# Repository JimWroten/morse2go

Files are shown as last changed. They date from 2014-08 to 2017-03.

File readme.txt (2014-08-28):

Morse2Go is a small portable device that helps people with disabilities communicate. 
Specifically, the target users include people with disabilities involving speech and 
movement. But by moving a finger, toe, arm, head or using a puff/sip mouth switch, 
a person can key text messages into the M2G. Their words will be displayed on a 
small LCD screen, smartphone or computer. 

The M2G is an Arduino Due project. The source code consists of three files m2g_1.ino,
m2g.cpp and m2g.h. In addition, the libraries Adafruit_CC3000 and Stopwatch are used,
in addition to the standard Arduino libraries.

See www.morse2go.org for more information.

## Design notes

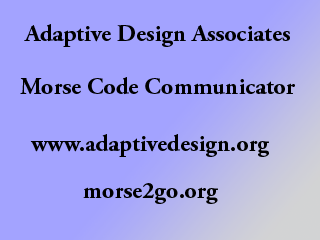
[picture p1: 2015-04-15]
m2g_2/m2g.bmp

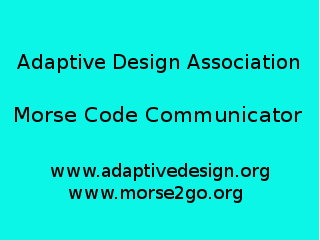
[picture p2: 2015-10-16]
m2g_21/m2g.bmp

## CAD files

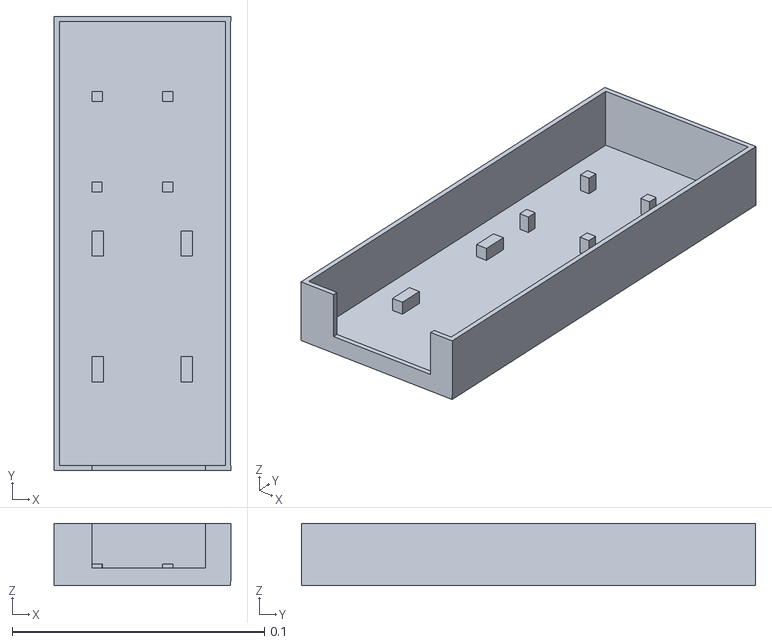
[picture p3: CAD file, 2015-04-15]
m2g_2_case/m2g_case.stl
0.07 x 0.18 x 0.0247

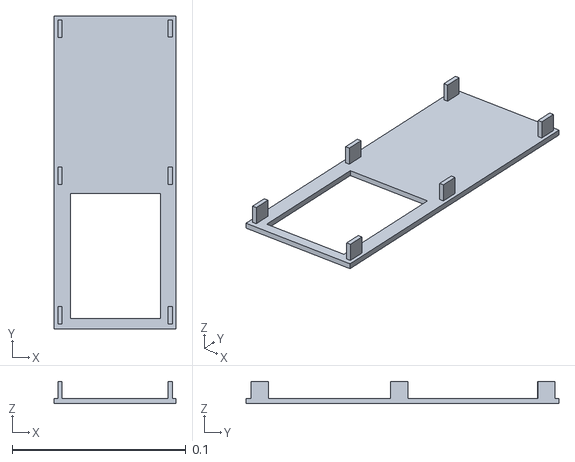
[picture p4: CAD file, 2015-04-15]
m2g_2_case/m2g_top.stl
0.07 x 0.18 x 0.0128

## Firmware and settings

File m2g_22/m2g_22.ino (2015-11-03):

/* Morse2Go
A communication device for persons with language and movement disabilities.
For more information, please visit -- www.morse2go.org

This device accepts Morse Code input from either one key switch or two keys
and translates the codes onto an LCD screen. Display can also be seen on a
Smartphone or a Computer Monitor.

The hardware is based on the Arduino Mega 2560 and Adafruit 2.8" TFT display.
Morse Code patterns and user defined abbreviations are stored on a micro SD card
so that code modifications can be made without changing program code.

Developed jointly by Adaptive Design Association, NYC (www.adaptivedesign.org),
and Jim Wroten, Technical Consultant (www.jimwroten.nyc).

This work is licensed 2015 by Jim Wroten (www.jimwroten.nyc) under a Creative
Commons Attribution-ShareAlike 4.0 International License. For more information
about this license, see www.creativecommons.org/licenses/by-sa/4.0/
-- Basically, you can use this software for any purpose for free,
as long as you say where you got it and that if you modify it, you don't remove
any lines above THIS line:
---------------------------------------------------------------

------------------ Release History  ---------------------------

9/6/14 Initial Release 1.0
  - basic functionality - user input of 1 or 2 button code
  - morse2go code table input from Google docs - support for mcode, scode and pcode
  - user input of timing values. persistent pcode values saved in usr_parm.csv file on Micro SD
  - basic checking of user input parmameters (pcode) upper and lower limits, 10% max change limits
  - /D delete - deletes the usr_parm.csv file and reboots. This brings in factory default timings
  - /L list - list current timing paramters
  - TODO: user input of short codes

10/1/14 Release 2.0
  - moved to Arduino Mega 2560 platform with Adafruit 2.8" TFT LCD shield and Micro SD card - reduces assembly complexity
  - added EMIC 2 text-to-speech module
  - construction note: Using the Adafruit 2.8" TFT with the Mega 2560 requires soldering closed the three ICSP jumpers,
  near the 6 pin jack. See: https://learn.adafruit.com/adafruit-2-8-tft-touch-shield-v2/connecting - search "Using with a Mega".
  It isn't necessary to cut the small line in between the #11, #12, #13 pads.

4/1/15 Release 2.1
  - Simplified user modified parameters - only saving the last change to parameters, which overrides the Google Doc parameters (pcodes)
  - Added pcodes /vc (voice)
  - removed one button operation - use button 1 for dit, button 2 for dah
  - added enter key and delete key (buttons 3 and 4)
  -   enter key - press to accept last entry in buffer. If there is no last entry, insert space, third space - say it
  -   delete key - press to delete current buffer. If buffer is empty, delete last character on screen, third delete clear screen

11/10/15 Release 2.2
  - Two Button and Four Button modes - a long press of button 1 is the same as a button 3 press. Long press of button 2 
    is the same as button 4. 
  - Added codes for space (..--), backspace (----), speak (.---.), and clear (.._..). These are defined on code.csv
  - Formatted the TFT screen when words wrap
  - Moved Word Work Area to fifth line of TFT, separating it from the message area (lines 1 - 4). This simplifies the software
    design and gives the user more focus on the bottom three lines of the display. 
  - Added Long Press user control. By entering one of 13 codes (:L3 to :L9 and :LA to :LF) user can vary the lenght of a long press from 
    0.3 seconds to 1.5 seconds, respectively. This new value is saved for the next reboot. 
  - Added Voice Param user contral. By entering one of the 9 codes (:V0 ot :V8) the user can change the voice of the Text-to-Speech module.
    This new value is saved for the next reboot.   
*/

#include <Adafruit_GFX.h>    // Core graphics library
#include "Adafruit_ILI9341.h" // 2.8" touch screen
#include <SPI.h>
#include <SD.h>
#include <StopWatch.h>
#include <EEPROM.h>
#include "m2g.cpp"

#define TFT_DC 9
#define TFT_CS 10
Adafruit_ILI9341 tft = Adafruit_ILI9341(TFT_CS, TFT_DC);

// MicroSD
const int chipSelect = 4;
#define SD_CS 4

// data structure of morse code
mcodes mcode;

// data structure of short code
scodes scode;

// data structure of parameter code
pcodes pcode;

// data structure of a single letter
char_stk char_s;

// data structure of word stack
word_stk word_s;

// data structure of message stack
message_stk message_s;

// stopwatch -- used to time switch press
StopWatch SW;

// length of a long press (minimum in milliseconds)
int LongPress;

// voice parm
int Voice;

// flag that is set if long press done
int LongPress1, LongPress2, LongPress3;

// pin number can be changed
const int inPin1 = 41;     // button 1 - dit
int buttonState1 = HIGH;  // button state - dit
int lastButtonState1 = HIGH;
long lastDebounceTime1 = 0;  // the last time pin 1 was toggled
int readingPin1;  // current reading switch 1

// pin number can be changed
const int inPin2 = 43;     // button 2 - dah
int buttonState2 = HIGH;  // button state - dah
int lastButtonState2 = HIGH;
long lastDebounceTime2 = 0;  // the last time pin 2 was toggled
int readingPin2;  // current reading switch 2

// pin number can be changed
const int inPin3 = 47;     // button 3 - enter
int buttonState3 = HIGH;  // button state - enter
int lastButtonState3 = HIGH;
long lastDebounceTime3 = 0;  // the last time pin 3 was toggled
int readingPin3;  // current reading switch 3
short timesPressed3 = 0; // times enter key pressed in a row

// pin number can be changed
const int inPin4 = 49;     // button 4 - delete
int buttonState4 = HIGH;  // button state - delete
int lastButtonState4 = HIGH;
long lastDebounceTime4 = 0;  // the last time pin 3 was toggled
int readingPin4;  // current reading switch 4
short timesPressed4 = 0; // times delete key pressed in a row

const long debounceDelay = DEBOUNCEDELAY;     // delay in milliseconds

// voice param
int pr_vc = PRVC;
int pr_fn = PRFN;

// EEPROM data 
int Adr = 0;
EEPromData Eep;

int inp_ch = -1;

// done once to load classes and setup
void setup()
{
  char *p;
  int i = 0, j = 0, n = 0, k, r, c;
  int mode;
  char buf[20], buf1[20];
  int v[NPARMS];
  float f_longPress, f_voice;

  // Open serial communications and wait for port to open:
  Serial.begin(9600);

  // Open serial communications for EMIC 2 Text to Speech module
  // Pin18 is TX pin - connect to SIN on EMIC 2
  // Pin19 is RX pin - connect to SOUT on EMIC 2
  // NOTE: This code is specific to Arduino Mega

  Serial1.begin(9600);
  Serial1.print('\n');             // Send a CR in case the system is already up
  delay(20);
  while (Serial1.read() != ':');   // When the Emic 2 has initialized and is ready, it will send a single ':' character, so wait here until we receive it
  Serial1.flush();                 // Flush the receive buffer

  // read EEPROM data
  EEPROM.get(Adr, Eep);

  if (Eep.ckvalue != CKVALUE) {  // initialize first time if never used
      for (i = 0 ; i < EEPROM.length() ; i++)
        EEPROM.write(i, 0);

      Eep.ckvalue = CKVALUE;
      Eep.LongPress = LongPress = LONGPRESS;
      Eep.Voice = Voice = VOICE; 
      for (i = 0; i < 10; i++) 
          Eep.v[i] = 0; 
      EEPROM.put(Adr, Eep);
      sprintf(buf, "eeprom initialized - first time use");
      Serial.println(buf); 
  }
  else {
      LongPress = Eep.LongPress;
      Voice = Eep.Voice; 
      sprintf(buf, "Voice: %d, Long Press: %d\n", Voice, LongPress);
      Serial.println(buf);
  }
  sprintf(buf, "N%d\n", Voice); 
  Serial1.print(buf);
  Serial1.flush();                 // Flush the receive buffer

  LongPress3 = 0;

  // input keys setup
  pinMode(inPin1, INPUT);
  pinMode(inPin2, INPUT);
  pinMode(inPin3, INPUT);
  pinMode(inPin4, INPUT);

  digitalWrite(inPin1, HIGH);
  digitalWrite(inPin2, HIGH);
  digitalWrite(inPin3, HIGH);
  digitalWrite(inPin4, HIGH);

  // for Micro SD
  pinMode(chipSelect, OUTPUT);

  // see if the card is present and can be initialized:
  if (!SD.begin(chipSelect)) {
    tft.println(F("Card failed, or not present"));
    // don't do anything more:
    return;
  }

  // load data file from Google Docs copied onto Micro SD
  ReadDataFile(CODE);

  // load user parameter file if it exists
  ReadParmFile(USR_PARM);

  // sort the codes
  mcode.sortcode();

  // setup TFT screen
  tft.begin();
  tft.setTextColor(ILI9341_BLACK);
  tft.setTextSize(2);  // font param

  tft.setRotation(1);
  bmpDraw("m2g.bmp", 0, 0);
  delay(2000);
  
  tft.fillScreen(0xFFFF);
  setcursor(1, -1, 4, 4, &c, &r);
  tft.print(F("M2G Version 2.2"));
  delay(1000);

  f_longPress = (float)LongPress / 1000.0;
  dtostrf(f_longPress, 3, 1, buf1);
  sprintf(buf, "Long Press %s Sec.", buf1); 
  tft.fillScreen(0xFFFF);
  setcursor(1, -1, 2, 4, &c, &r);
  tft.print(buf);
  delay(1000);
  
  Serial1.print("S M 2 G Version 2.2\n");
  tft.setTextSize(pr_fn);  // font param
  cls(0);
  show_labels(0, 0);

}

// repeat this forever, checking for a keypress or key release event
void loop() {

  char buf[SIZMESG], buf1[SIZMESG];
  int timebtn1, timebtn2, timebtn3, timebtn4;
  int Btn1, Btn2, Btn3, Btn4, PushCode, clen, lenmesg, CurRow1, ptr, valLP, valVOZ ;
  int speakit, speaklen, new_word, csize, lenpword;
  char speaktxt[MAXWORD_TXT];
  char pword[SIZPWORD];
  char smesg[SIZMESG];
  char *pword1, *tok;
  static int PrvRow;
  static char s[2] = " ";
  float f_longPress;

  // check button status
  readingPin1 = digitalRead(inPin1);
  readingPin2 = digitalRead(inPin2);
  readingPin3 = digitalRead(inPin3);
  readingPin4 = digitalRead(inPin4);

  Btn1 = Btn2 = Btn3 = Btn4 = 0;
  PushCode = 0;
  LongPress1 = LongPress2 = 0;

  //  Button 1 - 4 Pressed
  if ((readingPin1 == LOW && lastButtonState1 == HIGH) ||
      (readingPin2 == LOW && lastButtonState2 == HIGH) ||
      (readingPin3 == LOW && lastButtonState3 == HIGH) ||
      (readingPin4 == LOW && lastButtonState4 == HIGH)) {
    SW.reset(); // reset timer
    SW.start(); // start timer
  }

  // button 1 Released
  if (readingPin1 == HIGH && lastButtonState1 == LOW) {
    timebtn1 = SW.elapsed();

    if (timebtn1 > DEBOUNCEDELAY) {
      SW.stop();
      if (timebtn1 > LongPress)
        LongPress1 = 1;
      else {
        PushCode = 1;  // dot
        Btn1++;
      }
    }
    LongPress3 = 0;
  }

  // button 2 Released
  if (readingPin2 == HIGH && lastButtonState2 == LOW) {
    timebtn2 = SW.elapsed();

    if (timebtn2 > DEBOUNCEDELAY) {
      SW.stop();
      if (timebtn2 > LongPress)
        LongPress2 = 1;
      else {
        PushCode = 2;  // dash
        Btn2++;
      }
    }
    LongPress3 = 0;
  }

  // button 3 Released
  if (readingPin3 == HIGH && lastButtonState3 == LOW) {
    timebtn3 = SW.elapsed();

    if (timebtn3 > DEBOUNCEDELAY) {
      SW.stop();
      if (timebtn3 > LongPress && LongPress3 == 0) {
        LongPress3 = 1;
      }
      else if (timebtn3 > LongPress && LongPress3 == 1) {
        LongPress3 = 0;
      }
      else {
        Btn3++;
        LongPress3 = 0;
      }
    }
  }

  // button 4 Released
  if (readingPin4 == HIGH && lastButtonState4 == LOW) {
    timebtn4 = SW.elapsed();

    if (timebtn4 > DEBOUNCEDELAY) {
      SW.stop();
      Btn4++;
    }
    LongPress3 = 0;
  }

  // dit or dah pressed - show results at bottom of screen
  if (Btn1 || Btn2) {
    clen = char_s.push(PushCode);
    if (clen <= MAXDD) 
       inp_ch = show_cbuf();
    timesPressed3 = 0;
    timesPressed4 = 0;
    show_labels(timesPressed3, timesPressed4);
  }

  if (Btn3 || LongPress1) {
    timesPressed4 = 0;
    if (inp_ch == 'p' or timesPressed3 == 1) { // insert a space
      new_word = 1; // set new word flag
      lenmesg = -1;

      // get previous word entered 
      lenpword = word_s.get_pword(pword);

      // was this a short code or Long Press parm code? If so, display message
      if (lenpword > 0 && pword[0] == ':') {
        pword1 = pword + (char) 1;
        memset(buf, 0, SIZMESG); 
        if (lenpword == 3) { // it might be a Long Press param
           valLP = LongPressLookup(pword1); 
           if (valLP > 0) { // it was a Long Press param -- update global variable, EEPROM, and display new value
              LongPress = valLP;
              EepUpdate(1, LongPress);
              f_longPress = (float)LongPress / 1000.0;
              dtostrf(f_longPress, 3, 1, buf1);
              sprintf(buf, "Long Press %s Sec.", buf1);
           }
           valVOZ = VoiceLookup(pword1); 
           if (valVOZ > 0) { // it was a Voice param -- update global variable, EEPROM, and display new value
              Voice = valVOZ;
              EepUpdate(2, Voice);
              sprintf(buf1, "N%d\n", Voice);
              Serial1.print(buf1);
              Serial1.flush();                 // Flush the receive buffer
              sprintf(buf, "Voice Code is %d", Voice);
           }
        }
        if (!strlen(buf))  // it wasn't a Long Press or Voice param, try for a short code
           lenmesg = scode.getcode(pword1, buf);

        // not a code - display as is
        if (!strlen(buf)) 
            sprintf(buf, "%s ", pword);
           
        tok = strtok(buf, s);
        while (tok != NULL)  {
           strcpy(buf1, tok);
           message_s.push(buf1); 
           DisplayMessage();         
           tok = strtok(NULL, s);
        }        
      }
      else {

        // push word onto message stack 
        message_s.push(pword); 

        // display the message
        DisplayMessage(); 

      }

      // clear the word row
      cls(2);

      timesPressed3 = 2;
    }
    else if (timesPressed3 == 2 || inp_ch == '.' || inp_ch == 's') {  // enter pressed 3 times - speak
      memset(speaktxt, 0, MAXWORD_TXT); 
      speaklen = GetMessage(speaktxt);
      if (speaklen) {
        sprintf(buf, "S%s\n", speaktxt);
        Serial1.print(buf);
        Serial1.flush();                 // Flush the receive buffer
        Serial.println(buf); 
      }
      timesPressed3 = 0;
    }
    else if (inp_ch == 'b') {  // special case - backspace
      backspace();
      timesPressed3 = 1;
    }
    else if (inp_ch == 'c') {  // special case - clear screen
      cls(0);
      timesPressed3 = 0;
    }
    else if (inp_ch == -1) {
      timesPressed3 = 0;
    }
    else {
      CurRow1 = outch(inp_ch);  // normal case - display character
      timesPressed3 = 1;
    }

    inp_ch = -1;
    char_s.clear();
    clr_buf(3);
    show_labels(timesPressed3, timesPressed4);
  }

  if (Btn4 || LongPress2) {
    timesPressed3 = 1;    // changed 0 to 1 --- debug
    if (timesPressed4 == 0)  // delete character
      timesPressed4 = 1;
    else if (timesPressed4 == 1) {  // del pressed twice - backspace
      backspace();
      timesPressed4 = 2;
    }
    else if (timesPressed4 == 2) {  // del pressed 3 times - clear screen
      cls(0);
      timesPressed4 = 0;
    }
    inp_ch = -1;
    char_s.clear();
    clr_buf(3);
    show_labels(timesPressed3, timesPressed4);
  }

  lastButtonState1 = readingPin1;
  lastButtonState2 = readingPin2;
  lastButtonState3 = readingPin3;
  lastButtonState4 = readingPin4;
}

////////////////////////// End of Loop ///////////////////////////////////////////
// begin functions

// read datafile into classes
// fn - file name
void ReadDataFile(char *fn) {
  char str[100];
  char *p;

  char buf[100];
  sprintf(buf, "file %s", fn);
  Serial.println(buf);

  File dataFile = SD.open(fn);
  if (dataFile) {

    while ( SD_fgets (str, 100, dataFile) != NULL ) {

      // remove newline
      if ((p = strchr(str, '\n')) != NULL)
        * p = '\0';

      switch (str[0]) {
        case 'm':
          mcode.loadcode(str);  // load the morse code
          break;
        case 's':
          scode.loadcode(str);  // load the short code
          break;
        case 'p':
          pcode.loadcode(str);  // load the parameter code
          break;
      }
    }
  }
  dataFile.close();
}

// read the User Parm File for changes in MC input timing
//

void ReadParmFile(char *fn) {
  int j, len;
  char buf_pcode[BUFPCODE]; // buffer for pcode data file

  memset(buf_pcode, 0, BUFPCODE);

  File dataFile = SD.open(fn);

  if (dataFile) {
    j = (int)dataFile.size();
    dataFile.read(buf_pcode, (uint16_t)j);
    dataFile.close();
    pcode.loadparmcode(buf_pcode);
  }
}

// show labels below char buffer
void show_labels(int Lab3, int Lab4) {
  int r, c;

  // clear label line
  setcursor(1, -1, 2, 7, &c, &r);
  tft.fillRect(c, r, 320, 25, ILI9341_WHITE);
  tft.setTextSize(2);

  switch (Lab3) {
    case 0:
      if (inp_ch == -1)
        tft.setTextColor(0xEEEE);
      tft.println("<Enter>");
      break;
    case 1:
      tft.println("<Space>");
      break;
    case 2:
      tft.println("<Say It>");
      break;
  }
  setcursor(1, -1, 10, 7, &c, &r);
  tft.setTextColor(ILI9341_BLACK);

  switch (Lab4) {
    case 0:
      if (char_s.size() < 1)
        tft.setTextColor(0xEEEE);
      tft.println("<Delete>");
      break;
    case 1:
      tft.println("<Backspace>");
      break;
    case 2:
      tft.println("<Clear>");
      break;
  }
  tft.setTextColor(ILI9341_BLACK);
  tft.setTextSize(pr_fn);  // restore font size
}

// show what's in the char buffer on the bottom line
int show_cbuf() {
  long cval;
  char buf[MAXDD + 1], buf1[25], buf2[25], inp_ch, ch1[2];
  int n, i, k, rc, r, c;
  int ch[MAXDD + 1];

  cval = char_s.get_charval(n, ch);
  k = mcode.getcode(cval, &inp_ch);

  memset(buf, 0, MAXDD + 1);
  for (i = 0; i < n; i++) {
    ch1[0] = ch1[1] = 0;
    if (ch[i] == 1)
      ch1[0] = 219; // dot
    else if (ch[i] == 2)
      ch1[0] = 195;  // dash
    else
      ch1[0] = ' ';

    strcat(buf, ch1);
  }
  setcursor(1, -1, 3, 6, &c, &r);
  tft.println(buf);
  if (k > -1) {

    // clear the right side
    clr_buf(2);

    // write the new char
    tft.setTextColor(ILI9341_BLACK);

    // handles the special cases of space, backspace, speak, and CLS
    switch (inp_ch) {
      case 'p':
        strcpy(buf1, "Space");
        break;
      case 'b':
        strcpy(buf1, "Bksp");
        break;
      case 's':
        strcpy(buf1, "Speak");
        break;
      case 'c':
        strcpy(buf1, "CLS");
        break;
      default:
        sprintf(buf1, "%c", inp_ch);
    }
    setcursor(1, -1, 11, 6, &c, &r);
    tft.println(buf1);
    rc = inp_ch;
  }
  else { // char not found - clear space
    clr_buf(2);
    rc = -1;
  }
  return rc;
}

// clear the screen and buffers
// mode 0 - clear buffers and print "OK"
// mode 1 - clear only char buff, no "OK"
// mode 2 - clear the Word line
// mode 3 - clear the message area (lines 1-4) 
void cls(int mode) {
  int row = WORDROW * SIZER;
  int cols = NCOL * SIZEC;
  int msgRows = SIZER * 5;  

  if (mode == 0) {
    message_s.clear(); 
    word_s.clear();
    char_s.clear();
    tft.fillScreen(0xFFFF);
    tft.setCursor(0, (WORDROW * SIZER));
    tft.print("OK>");
    CursorMgt(1, 1); // turn on cursor
  }
  else if (mode == 1)
    tft.fillScreen(0xFFFF);
  else if (mode == 2) { // clear the Word line 
    word_s.clear();
    char_s.clear();
    tft.fillRect(0, row, cols, SIZER, ILI9341_WHITE);
    tft.setCursor(0, (WORDROW * SIZER));
    tft.print("OK>");
    CursorMgt(1, 1); // turn on cursor
  }
  else if (mode == 3) {  // clear the Message Area
    tft.fillRect(0, 0, cols, msgRows, ILI9341_WHITE);
  } 
}

// clear buffer area - side=1 left, side=2 right, both=3
void clr_buf(int side) {
  int r, c;

  if (side == 1) { // left
    setcursor(1, -1, 0, 6, &c, &r);
    tft.fillRect(c, r, 199, 25, ILI9341_WHITE);
  }
  else if (side == 2) { // right
    setcursor(1, -1, 11, 6, &c, &r);
    tft.fillRect(c, r, 100, 50, ILI9341_WHITE);
  }
  else {
    setcursor(1, -1, 0, 6, &c, &r);
    tft.fillRect(c, r, 320, 25, ILI9341_WHITE);
  }
}
// backspace on the tft -
// -1 flags to erase last character and pop the stack
void backspace() {
  outch(-1);
}

// Display Message in upper part of screen
int DisplayMessage() {
    static int Row, Col;
    int tftcol, tftrow; 
    int ptr, len, newcol;
    char word[MAXWORD]; 
    char buf[50];

    ptr = message_s.get_ptr(); 
    message_s.get_msg(-1, word); 
    len = strlen(word); 

    // setup row and col for next word
    if (ptr == 1) {
        Row = 0; 
        Col = 0; 
    }
    else {
        newcol = Col + len; 
        if (newcol >= NCOL) {
            Col = 0; 
            Row++;
            if (Row > 4) {
                tftcol = (NCOL-3) * SIZEC;
                tftrow = 4 * SIZER;
                tft.setCursor(tftcol, tftrow);
                tft.println("..");
                delay(3000); 
                cls(3);
                Col = 0; 
                Row = 0; 
            }
        }
    }
    
    tftcol = Col * SIZEC;
    tftrow = Row * SIZER;
    tft.setCursor(tftcol, tftrow);
    tft.println(word);

    // ready for the next word
    Col += len + 1; 
}

// return the entire message in msg
int GetMessage(char *msg) {
    int i, j, len; 
    char buf[MAXWORD]; 

    i = message_s.get_ptr();

    for (j=0; j < i; j++) {
        message_s.get_msg(j, buf);
        len = strlen(msg) + strlen(buf) + 1; 
        if (len < MAXWORD_TXT) {
            strcat(msg, buf); 
            if (j)
                strcat(msg, " "); 
        }
    }
    i = strlen(msg); 
    return i; 
}
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

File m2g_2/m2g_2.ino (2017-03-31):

/* Morse2Go 
A communication device for persons with language and movement disabilities.
For more information, please visit -- www.morse2go.org

This device accepts Morse Code input from either one key switch or two keys
and translates the codes onto an LCD screen. Display can also be seen on a
Smartphone or a Computer Monitor. 

The hardware is based on the Arduino Due and Hitachi HD44780 20X4 LCD display.
Morse Code patterns and user defined abbreviations are input from a micro SD card.

Developed jointly by Adaptive Design Associates, NYC (www.adaptivedesign.org), 
Hall of Science Amateur Radio Club (www.hosarc.org),
and Jim Wroten, Technical Consultant (www.jimwroten.com).

This work is licensed 2014 by Jim Wroten ( www.jimwroten.com ) under a Creative 
Commons Attribution-ShareAlike 4.0 International License. For more information 
about this license, see www.creativecommons.org/licenses/by-sa/4.0/ 
-- Basically, you can use this software for any purpose for free, 
as long as you say where you got it and that if you modify it, you don't remove
any lines above THIS line:   -------------------------------------------------

------------------ Release History  ---------------------------

9/6/14 Initial Release 1.0 
  - basic functionality - user input of 1 or 2 button code
  - morse2go code table input from Google docs - support for mcode, scode and pcode
  - user input of timing values. persistent pcode values saved in usr_parm.csv file on Micro SD
  - basic checking of user input parmameters (pcode) upper and lower limits, 10% max change limits 
  - /U undo - removes last timing parameter entered
  - /D delete - deletes the usr_parm.csv file and reboots. This brings in factory default timings
  - /L list - list current timing paramters 
  - TODO: user input of short codes
  -      user input of short codes

10/1/13 Release 2.0


*/

#include <Adafruit_GFX.h>    // Core graphics library
#include "Adafruit_ILI9341.h" // Hardware-specific library
#include <SPI.h>
#include <SD.h>
#include <StopWatch.h>
#include "m2g.cpp"

#define TFT_DC 9
#define TFT_CS 10
Adafruit_ILI9341 tft = Adafruit_ILI9341(TFT_CS, TFT_DC);


// MicroSD
const int chipSelect = 4;

int resetPin = 6;  // reset pin - 1k resistor goes to RESET pin

// data structure of morse code
mcodes mcode;

// data structure of short code
scodes scode;

// data structure of parameter code
pcodes pcode;

// data structure of a single letter
char_stk char_s;

// data structure of word stack
word_stk word_s;

// stopwatches -- used to time switch presses
// SW[0] - intercharacter time
// SW[1] - interword time
StopWatch SW[2];

// button timer variables - triggered by ISR
volatile long btn1_time;
volatile byte btn1_evnt = 0;
volatile byte btn1_state = HIGH;

volatile long btn2_time;
volatile byte btn2_evnt = 0;
volatile byte btn2_state = HIGH;

// these can be changed
const int inPin1 = 20;     // button 1 - dit
const int inPin2 = 21;     // button 2 - dah
const int inSwit = 49;     // switch - 1 button or 2 button

// time constants - defined, but overridden by code or user file (in that order)
unsigned ms_do = MSDO;
unsigned ms_da = MSDA;
unsigned ms_lt = MSLT;
unsigned ms_cl = MSCL;

int readingPin1;           // the current readingPin1 from the input pin
int readingPin2;           // the current readingPin2 from the input pin
int readingSwit;           // the current from the switch
int SwitchMode;            // value of 1 or 2 button mode switch
int loopctr = 0;

// done once to load classes and setup     
void setup()
{
  char *p;
  int i = 0, j = 0, n = 0, k;
  int mode;

  // Open serial communications and wait for port to open:
  Serial.begin(9600);

  // input keys setup  
  pinMode(inPin1, INPUT);
  pinMode(inPin2, INPUT);
  pinMode(inSwit, INPUT);

 digitalWrite(inPin1, HIGH);
 digitalWrite(inPin2, HIGH);
 digitalWrite(inSwit, HIGH);
 
 // Interrupt for button presses
 attachInterrupt(3, ckbtn1, CHANGE);  // button 1  
 attachInterrupt(2, ckbtn2, CHANGE);  // button 2
 
  Serial.println("Starting...");
  delay(1000);
  
  // setup TFT screen 
  tft.begin();
  tft.fillScreen(0xFFFF);
  tft.setCursor(0, 0);
  tft.setTextColor(ILI9341_BLACK);  
  tft.setTextSize(2);
  tft.setRotation(1);
  tft.print("tft starting"); 

  // for Micro SD
  pinMode(chipSelect, OUTPUT);

  // see if the card is present and can be initialized:
  if (!SD.begin(chipSelect)) {
    tft.println(F("Card failed, or not present"));
    // don't do anything more:
    return;
  }

  // initialize reset
  //digitalWrite(resetPin, HIGH);
  //delay(20);
  //pinMode(resetPin, OUTPUT);
  
  //k = helloFile(2);
  k = 0;
  tft.setCursor(0, 100);
  tft.print("tft init"); 
  
  // Setup LCD size - send out hello message
  if (k == 0) {
    tft.setCursor(0, 0);
    tft.fillScreen(0xFFFF);
    tft.print(F("Adaptive Design"));
    tft.setCursor(0, 20);
    tft.print(F("Assoc. & HOSARC"));
    tft.setCursor(0, 40);
    tft.print(F("m2g - morse2go.org"));
    tft.setCursor(0, 60);
    tft.print(F("Version 2.0"));
    // show the hello message
    delay(2000);
  }

  //k = helloFile(0); // delete for next boot

  tft.fillScreen(0xFFFF);
  tft.setCursor(0, 0);
  tft.print(F("OK>"));

  word_s.clear();
  char_s.clear();
    
  // start keyboard emulation
  //Keyboard.begin();
  
  // SwitchMode == HIGH, use 1 button mode, LOW is for 2 button mode
  readingSwit = digitalRead(inSwit);
  if (readingSwit == LOW)
     SwitchMode = LOW;
  else
     SwitchMode = HIGH; 

  // load data file from Google Docs copied onto Micro SD
  ReadDataFile(CODE);
  
  // load user parameter file if it exists
  ReadParmFile(USR_PARM);

  // setup timing variables
  setup_timing();

  // sort the codes
  mcode.sortcode();

}
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

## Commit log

2014-10-09 M2G Version 2
    Changed to Arduino Mega and 2.8" TFT Screen. Added EMIC 2 Text to Speech
    Module.
2015-01-07 Version 2
    Moved to Arduino Mega 2580, added EMIC 2 Text to Speech module
2015-02-14 Added comments
    Added comments about TFT bridge soldering.
2015-04-15 M2G Version 2.1
    Simplified interface - now uses 4 buttons (dot, dash, enter, delete).
    Remove interrupt handler (buggy) and use simpler loop handler.
    [m2g.cpp, m2g_2.ino]
2015-04-15 M2G STL Files
    M2G STL Files to print the case on a 3D printer.
    [m2g_case.stl, m2g_top.stl]
